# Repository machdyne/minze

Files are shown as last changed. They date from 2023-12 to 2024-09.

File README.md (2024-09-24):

# Minze Computer

Minze is an FPGA computer designed by Lone Dynamics Corporation.

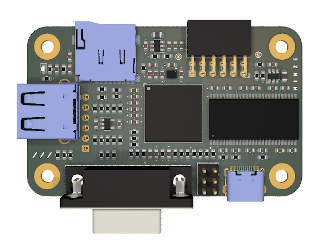
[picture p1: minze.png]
Minze Computer


This repo contains schematics, PCB layouts, pinouts, a 3D-printable case, example gateware and documentation.

Find more information on the [Minze product page](https://machdyne.com/product/minze-computer/).

## Programming Minze

Minze has a JTAG interface and ships with a [DFU bootloader](https://github.com/machdyne/tinydfu-bootloader) that allows the included flash [MMOD](https://machdyne.com/product/mmod) to be programmed over the USB-C port.

### DFU

The DFU bootloader is available for 5 seconds after power-on, issuing a DFU command during this period will stop the boot process until the DFU device is detached. If no command is received the boot process will continue and the user gateware will be loaded.

Install [dfu-util](http://dfu-util.sourceforge.net) (Debian/Ubuntu):

```
$ sudo apt install dfu-util
```

Update the user gateware on the flash MMOD:

```
$ sudo dfu-util -a 0 -D image.bit
```

Detach the DFU device and continue the boot process:

```
$ sudo dfu-util -a 0 -e
```

It is possible to update the bootloader itself using DFU but you shouldn't attempt this unless you have a JTAG programmer (or another method to program the MMOD) available, in case you need to restore the bootloader.

### JTAG

These examples assume you're using a "USB Blaster" JTAG cable, see the header pinout below. You will need to have [openFPGALoader](https://github.com/trabucayre/openFPGALoader) installed.

Program the configuration SRAM:

```
openFPGALoader -c usb-blaster image.bit
```

Program the flash MMOD:

```
openFPGALoader -f -c usb-blaster images/bootloader/tinydfu_minze.bit
```

## Blinky 

Building the blinky example requires [Yosys](https://github.com/YosysHQ/yosys), [nextpnr-ecp5](https://github.com/YosysHQ/nextpnr) and [Project Trellis](https://github.com/YosysHQ/prjtrellis).

Assuming they are installed, you can simply type `make` to build the gateware, which will be written to output/blinky.bin. You can then use [openFPGALoader](https://github.com/trabucayre/openFPGALoader) or dfu-util to write the gateware to the device.

## Linux

See the [Kakao Linux](https://github.com/machdyne/kakao) repo for the latest instructions.

### Prebuilt Images

Prebuilt gateware capable of running Linux is available in the `images/v1` directory.

These images support a serial console on the PMOD socket. You can use a standard USB-UART PMOD to access the BIOS, boot messages and serial console.

### Building Linux-capable Gateware

Please follow the setup instructions in the [linux-on-litex-vexriscv](https://github.com/litex-hub/linux-on-litex-vexriscv) repo and then:

1. Build the Linux-capable gateware:

```
$ cd linux-on-litex-vexriscv
$ ./make.py --board=minze --dcache-size=64 --icache-size=64 --uart-baudrate=115200 --build
$ ls build/minze
```

2. Write the gateware to the MMOD using USB DFU:

```
$ sudo dfu-util -a 0 -D build/minze/gateware/minze.bit
```

3. Copy the device tree binary `build/minze/minze.dtb` to a FAT-formatted MicroSD card.

## JTAG Header

The 3.3V JTAG header can be used to program the FPGA SRAM as well as the MMOD flash memory. It can also be used to provide power (5V) to the board.

```
6 5
4 3
2 1
```

| Pin | Signal |
| --- | --- |
| 1 | TCK |
| 2 | TDI |
| 3 | TDO |
| 4 | TMS |
| 5 | 5V0 |
| 6 | GND |

## Board Revisions

| Revision | Notes |
| --- | ----- |
| V1 | Initial production version |

## License

The contents of this repo are released under the [Lone Dynamics Open License](LICENSE.md) with the following exceptions:

- The KiCad design files contain parts of the [kicad-pmod](https://github.com/mithro/kicad-pmod) library which is released under the [Apache License, Version 2.0](https://www.apache.org/licenses/LICENSE-2.0.html).

- The KiCad design files may contain symbols and footprints released under other licenses; please contact us if we've failed to give proper attribution.

Note: You can use these designs for commercial purposes but we ask that instead of producing exact clones, that you either replace our trademarks and logos with your own or add your own next to ours.

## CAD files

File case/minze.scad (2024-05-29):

/*
 * Minze Case
 * Copyright (c) 2022 Lone Dynamics Corporation. All rights reserved.
 *
 * required hardware:
 *  - 4 x M3 x 25mm countersunk bolts
 *  - 4 x M3 nuts
 *
 */

$fn = 100;

board_width = 42;
board_thickness = 1.5;
board_length = 68;
board_height = 1.6;
board_spacing = 2;

wall = 1.5;

top_height = 15;
bottom_height = 10.5;

translate([wall,wall,0]) mdm_board();

translate([0,0,15])
	mdm_case_top();

translate([0,0,-15])
	mdm_case_bottom();

module mdm_board() {
	
	difference() {
		color([0,0.5,0])
			roundedcube(board_width,board_length,board_thickness,5);
		translate([5, 5, -1]) cylinder(d=3.2, h=10);
		translate([5, 68-5, -1]) cylinder(d=3.2, h=10);
		translate([42-5, 5, -1]) cylinder(d=3.2, h=10);
		translate([42-5, 68-5, -1]) cylinder(d=3.2, h=10);
	}	
	
}

module mdm_case_top() {

	// supports
	translate([wall, wall, 0]) {
		translate([40.5,53.7-(9.5/2)-1,0]) cube([1,1,14.9]);
		translate([40.5,53.7-(9.5/2)-8.45,0]) cube([1,1,14.9]);
	}
	
	difference() {
				
		color([0.5,0.5,0.5])
			roundedcube(board_width+(wall*2),board_length+(wall*2),top_height,5);

		// cutouts
			
		translate([2,9.5,-2])
			roundedcube(board_width-1.25,board_length-16,14.5,5);

		translate([9.5,2,-2])
			roundedcube(board_width-16,board_length,10.25,5);			
	
		translate([wall, wall, 0]) {

			// vents
			translate([42/2-(15/2),50,0]) rotate([0,0,-10]) cube([15,1,20]);
			translate([42/2-(15/2),45,0]) rotate([0,0,-10]) cube([15,1,20]);
			translate([42/2-(15/2),40,0]) rotate([0,0,-10]) cube([15,1,20]);			
	
			// USBC
			translate([30,53.7-(9.5/2),0]) cube([30,9.5,3.5]);

			// VGA
			translate([30,25-(31/2),-1]) cube([30,31,12.5+1]);
			
			// USBA
			translate([21-(15/2),-5,0]) cube([15,10,7.2+1]);
	
			// SD
			translate([-10,19.5-(15/2),-2]) cube([15,15,2+2]);
			
			// PMODA
			translate([-10,47.15-(16/2),0]) cube([25,16,5.1]);
			
			// bolt holes
			translate([5, 5, -21]) cylinder(d=3.5, h=40);
			translate([5, 68-5, -21]) cylinder(d=3.5, h=40);
			translate([42-5, 5, -20]) cylinder(d=3.5, h=40);
			translate([42-5, 68-5, -21]) cylinder(d=3.5, h=40);

			// flush mount bolt holes
			translate([5, 5, top_height-1.5]) cylinder(d=5.25, h=4);
			translate([5, 68-5, top_height-1.5]) cylinder(d=5.25, h=4);
			translate([42-5, 5, top_height-1.5]) cylinder(d=5.25, h=4);
			translate([42-5, 68-5, top_height-1.5]) cylinder(d=5.25, h=4);

			// minze text
			rotate(270)
				translate([-22.5,19,top_height-0.5])
					linear_extrude(1)
						text("M I N Z E", size=4, halign="center",
							font="Ubuntu:style=Bold");

		}
		
	}	
}

module mdm_case_bottom() {
	
	difference() {
		color([0.5,0.5,0.5])
			roundedcube(board_width+(wall*2),board_length+(wall*2),bottom_height,5);
		
		// cutouts
		translate([3,10,1.5])
			roundedcube(board_width-3,board_length-17,10,5);
				
		translate([10.5,2.5,1.5])
			roundedcube(board_width-17.5,board_length-2,10,5);

		translate([wall, wall, 0]) {
			
		// board cutout
		translate([0,0,bottom_height-board_height])
			roundedcube(board_width+0.2,board_length+0.2,board_height+1,2.5);

		translate([wall, wall, 0]) {

			// USBC
			translate([30.5,43,5]) cube([10.20,15,10.5+1]);

		}

		// bolt holes
		translate([5, 5, -11]) cylinder(d=3.2, h=25);
		translate([5, 68-5, -11]) cylinder(d=3.2, h=25);
		translate([42-5, 5, -11]) cylinder(d=3.2, h=25);
		translate([42-5, 68-5, -11]) cylinder(d=3.2, h=25);

		// nut holes
		translate([5, 5, -0.75]) cylinder(d=7, h=4, $fn=6);
		translate([5, 68-5, -0.75]) cylinder(d=7, h=4, $fn=6);
		translate([42-5, 5, -0.75]) cylinder(d=7, h=4, $fn=6);
		translate([42-5, 68-5, -0.75]) cylinder(d=7, h=4, $fn=6);

		}
		
	}	
}

// https://gist.github.com/tinkerology/ae257c5340a33ee2f149ff3ae97d9826
module roundedcube(xx, yy, height, radius)
{
    translate([0,0,height/2])
    hull()
    {
        translate([radius,radius,0])
        cylinder(height,radius,radius,true);

        translate([xx-radius,radius,0])
        cylinder(height,radius,radius,true);

        translate([xx-radius,yy-radius,0])
        cylinder(height,radius,radius,true);

        translate([radius,yy-radius,0])
        cylinder(height,radius,radius,true);
    }
}

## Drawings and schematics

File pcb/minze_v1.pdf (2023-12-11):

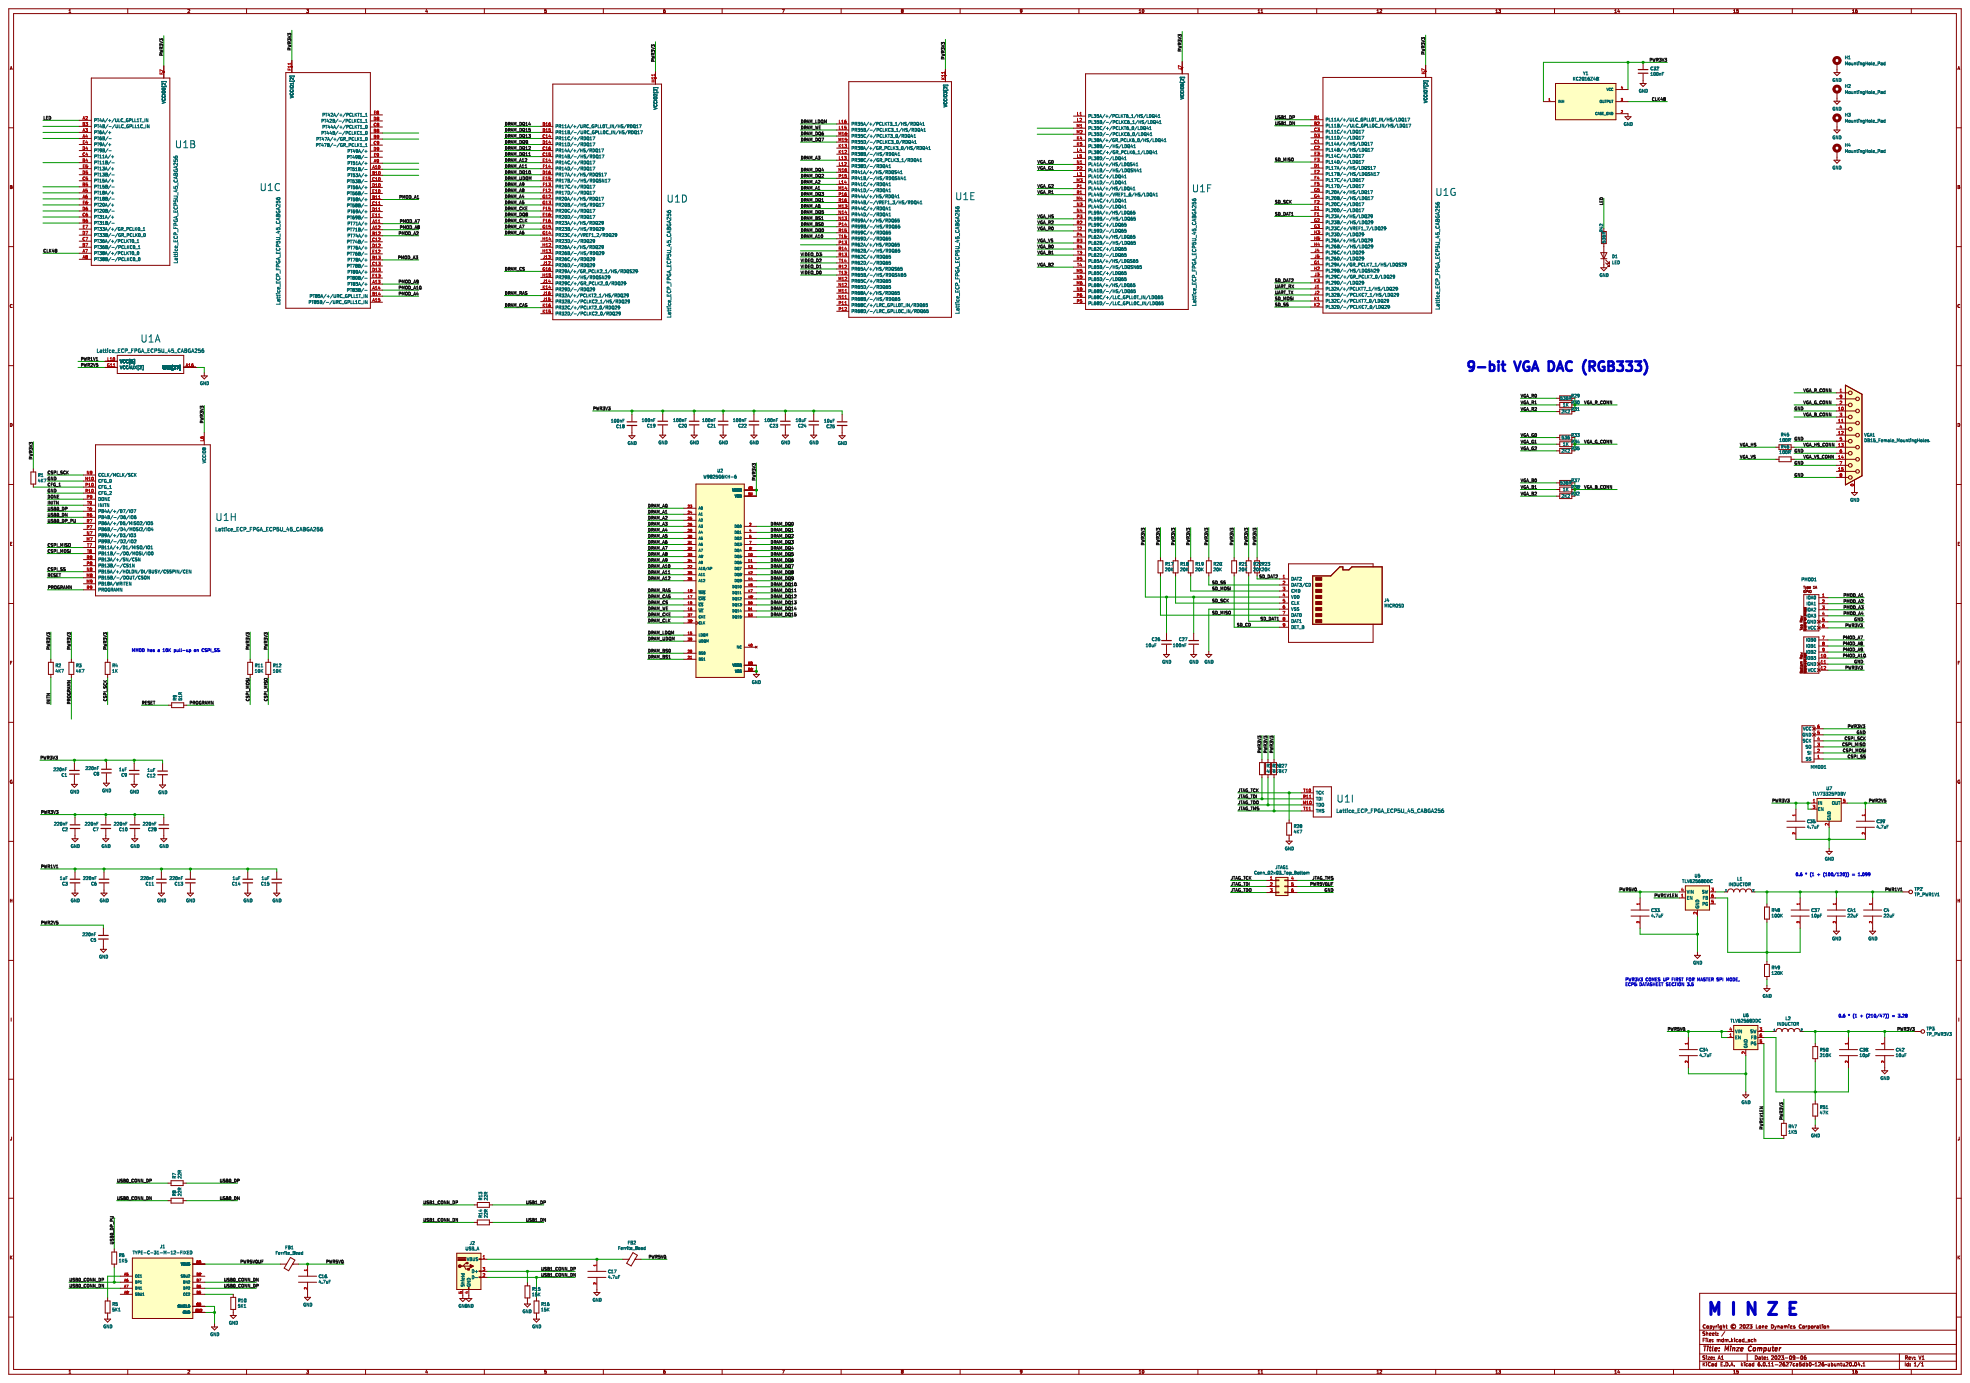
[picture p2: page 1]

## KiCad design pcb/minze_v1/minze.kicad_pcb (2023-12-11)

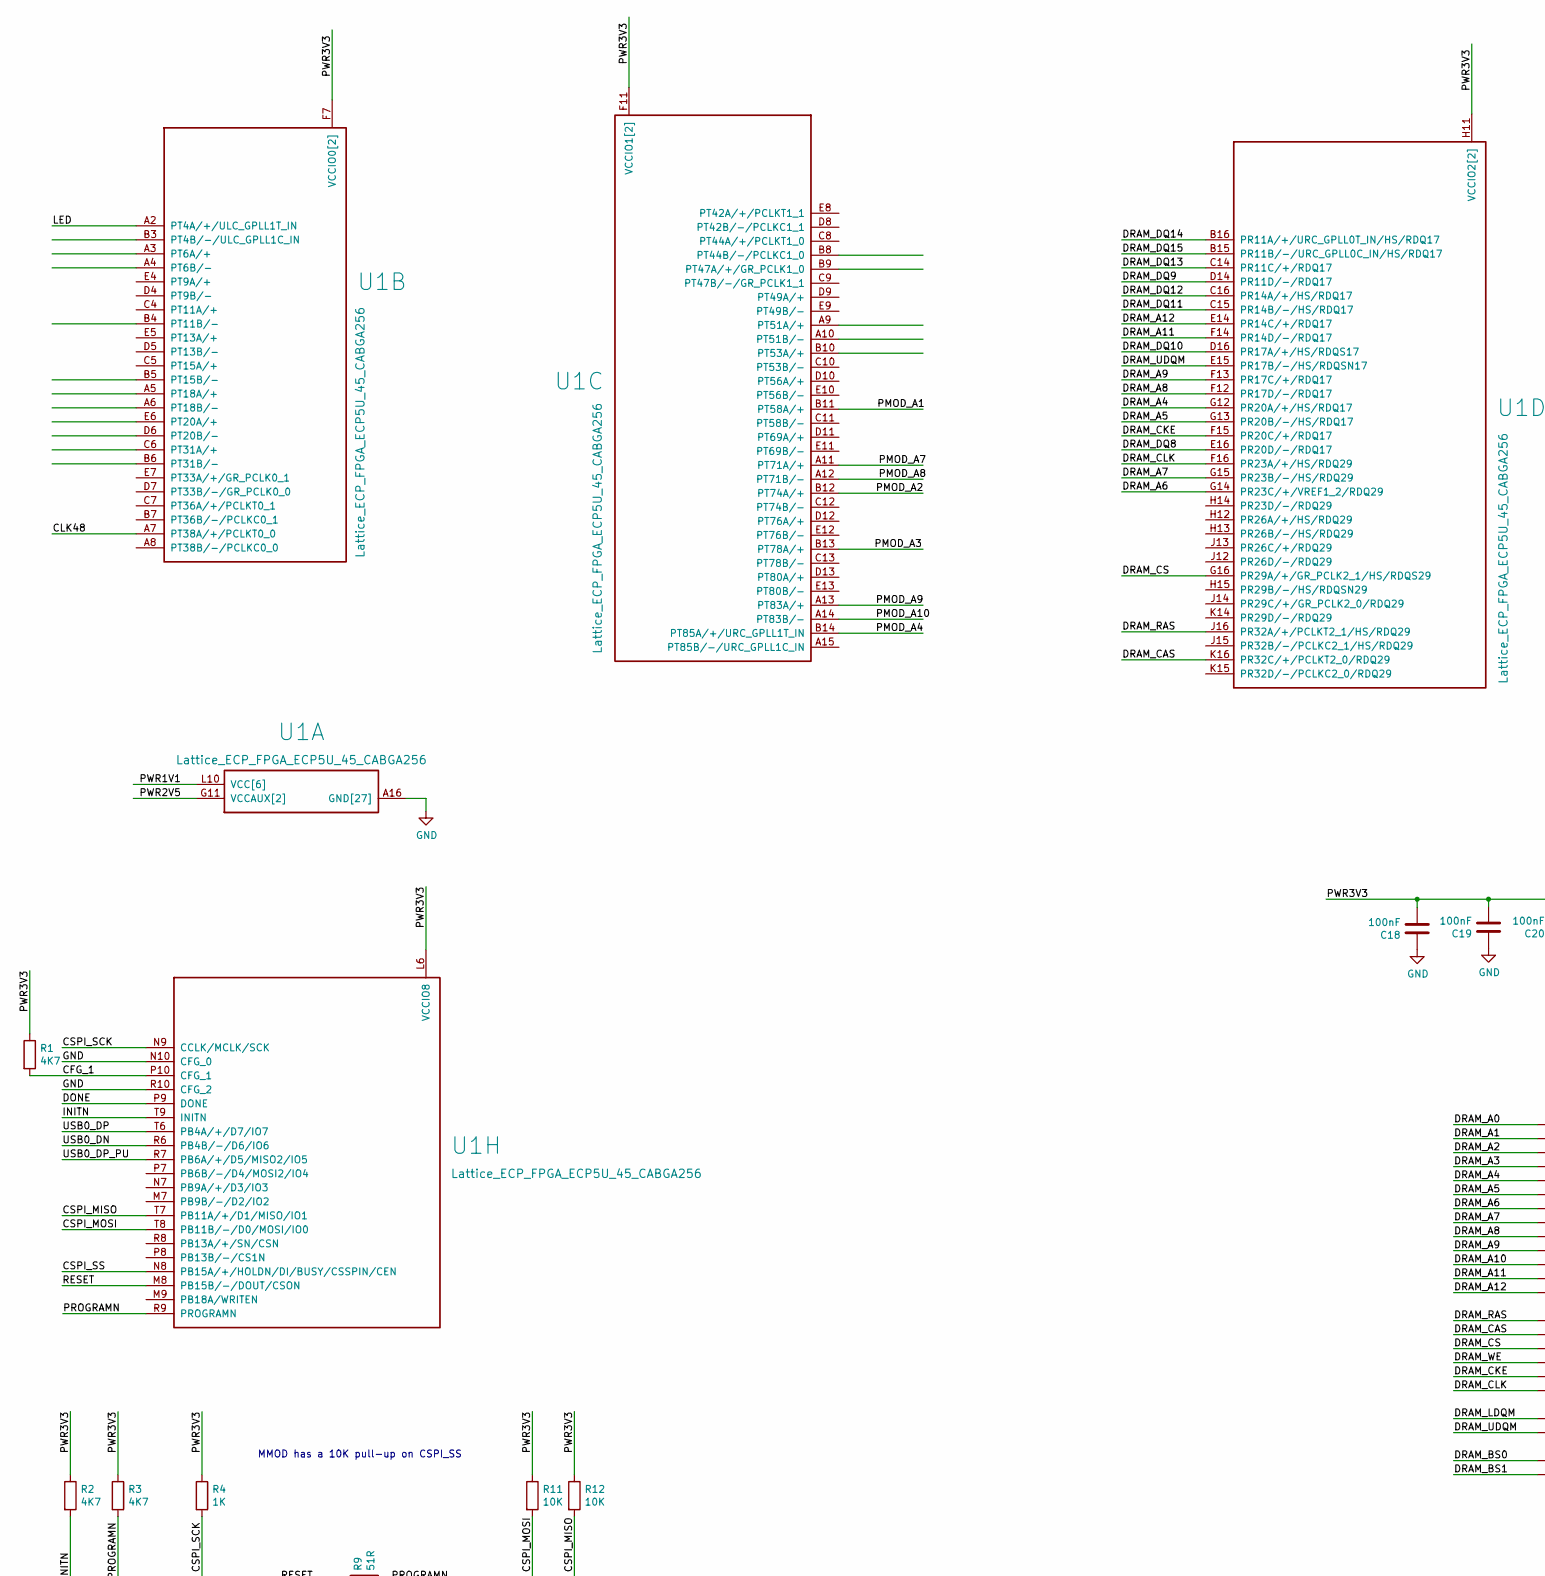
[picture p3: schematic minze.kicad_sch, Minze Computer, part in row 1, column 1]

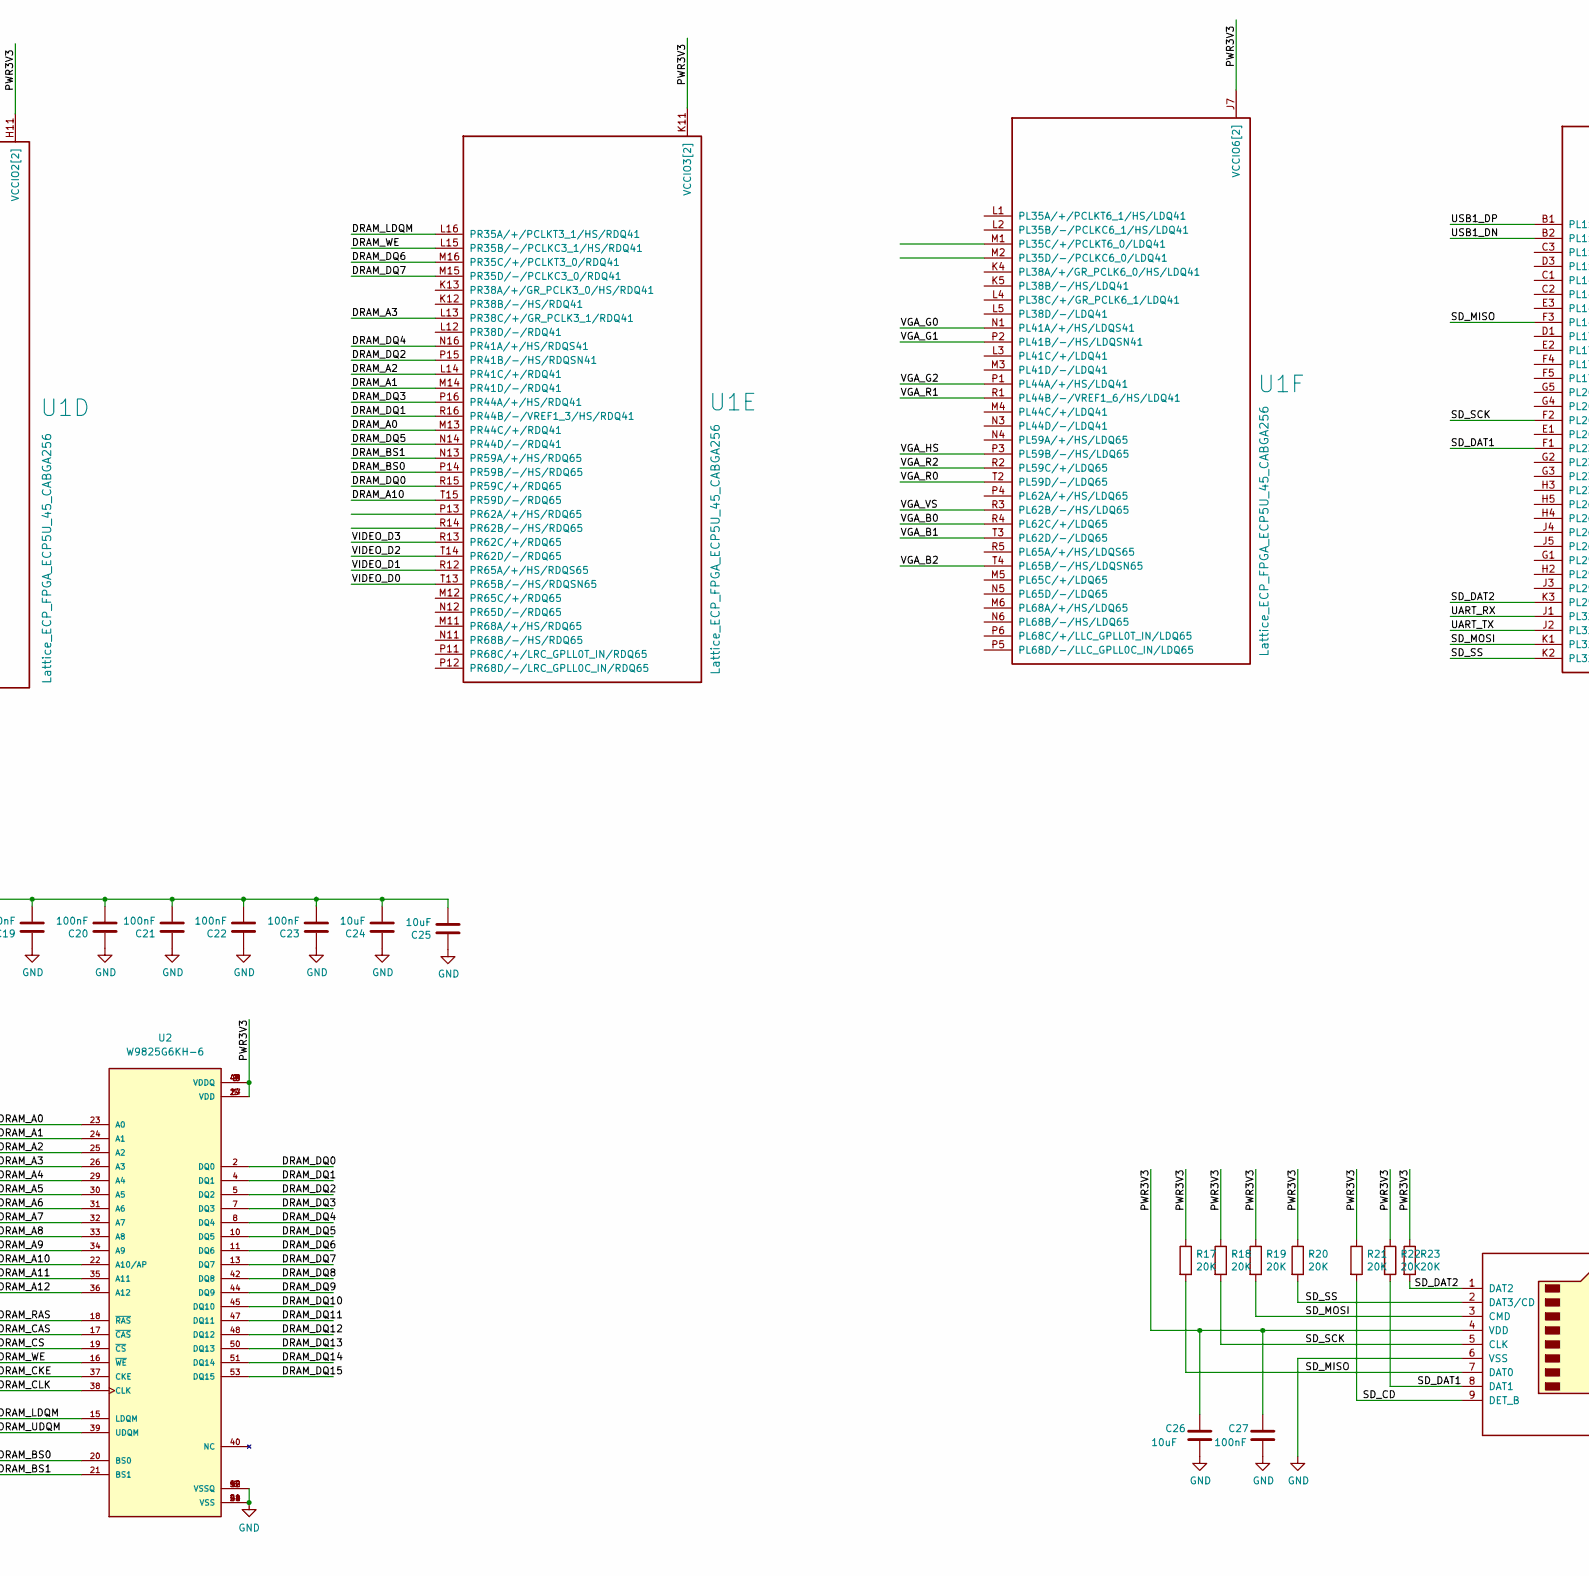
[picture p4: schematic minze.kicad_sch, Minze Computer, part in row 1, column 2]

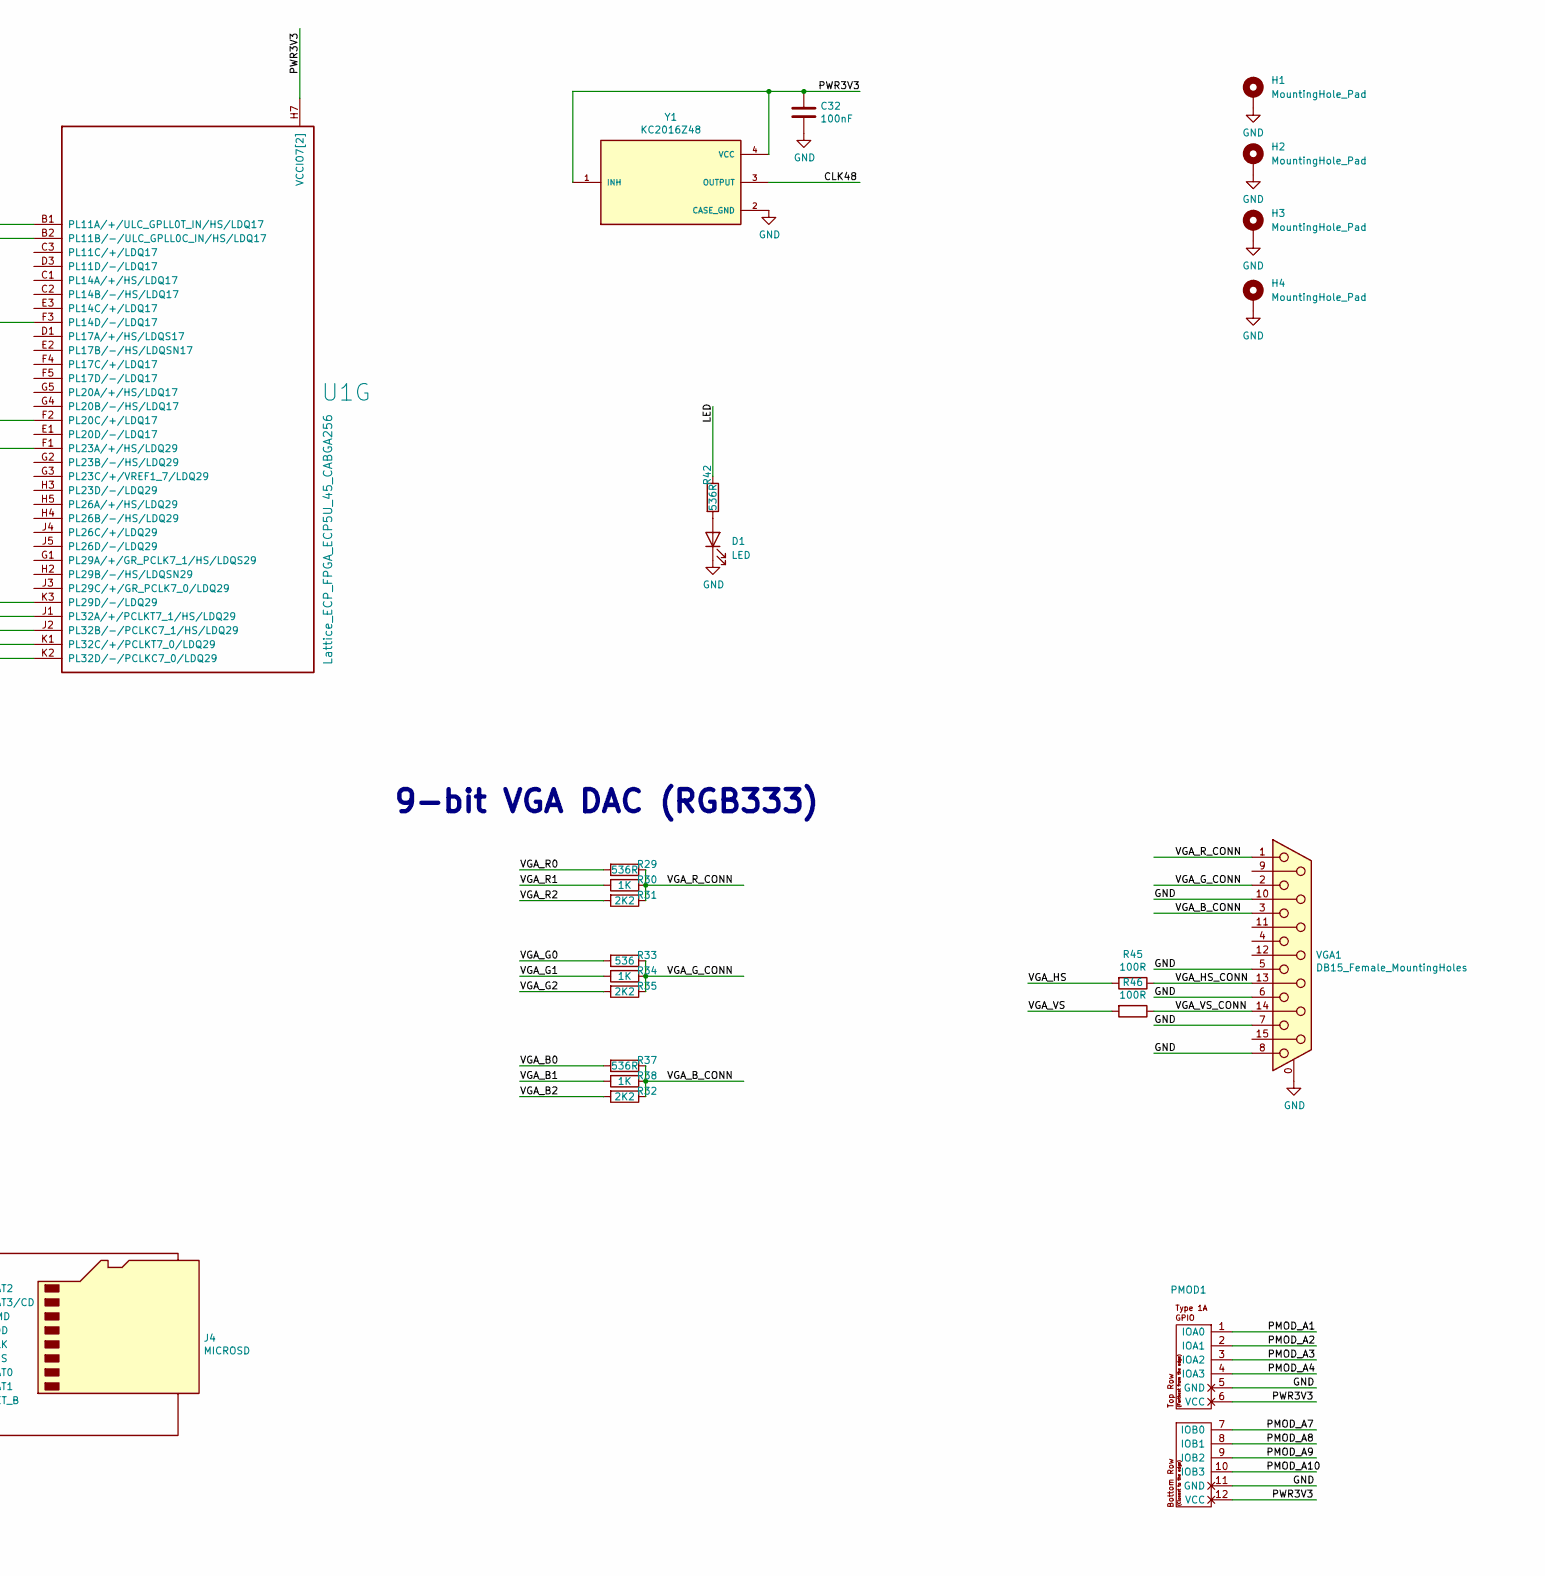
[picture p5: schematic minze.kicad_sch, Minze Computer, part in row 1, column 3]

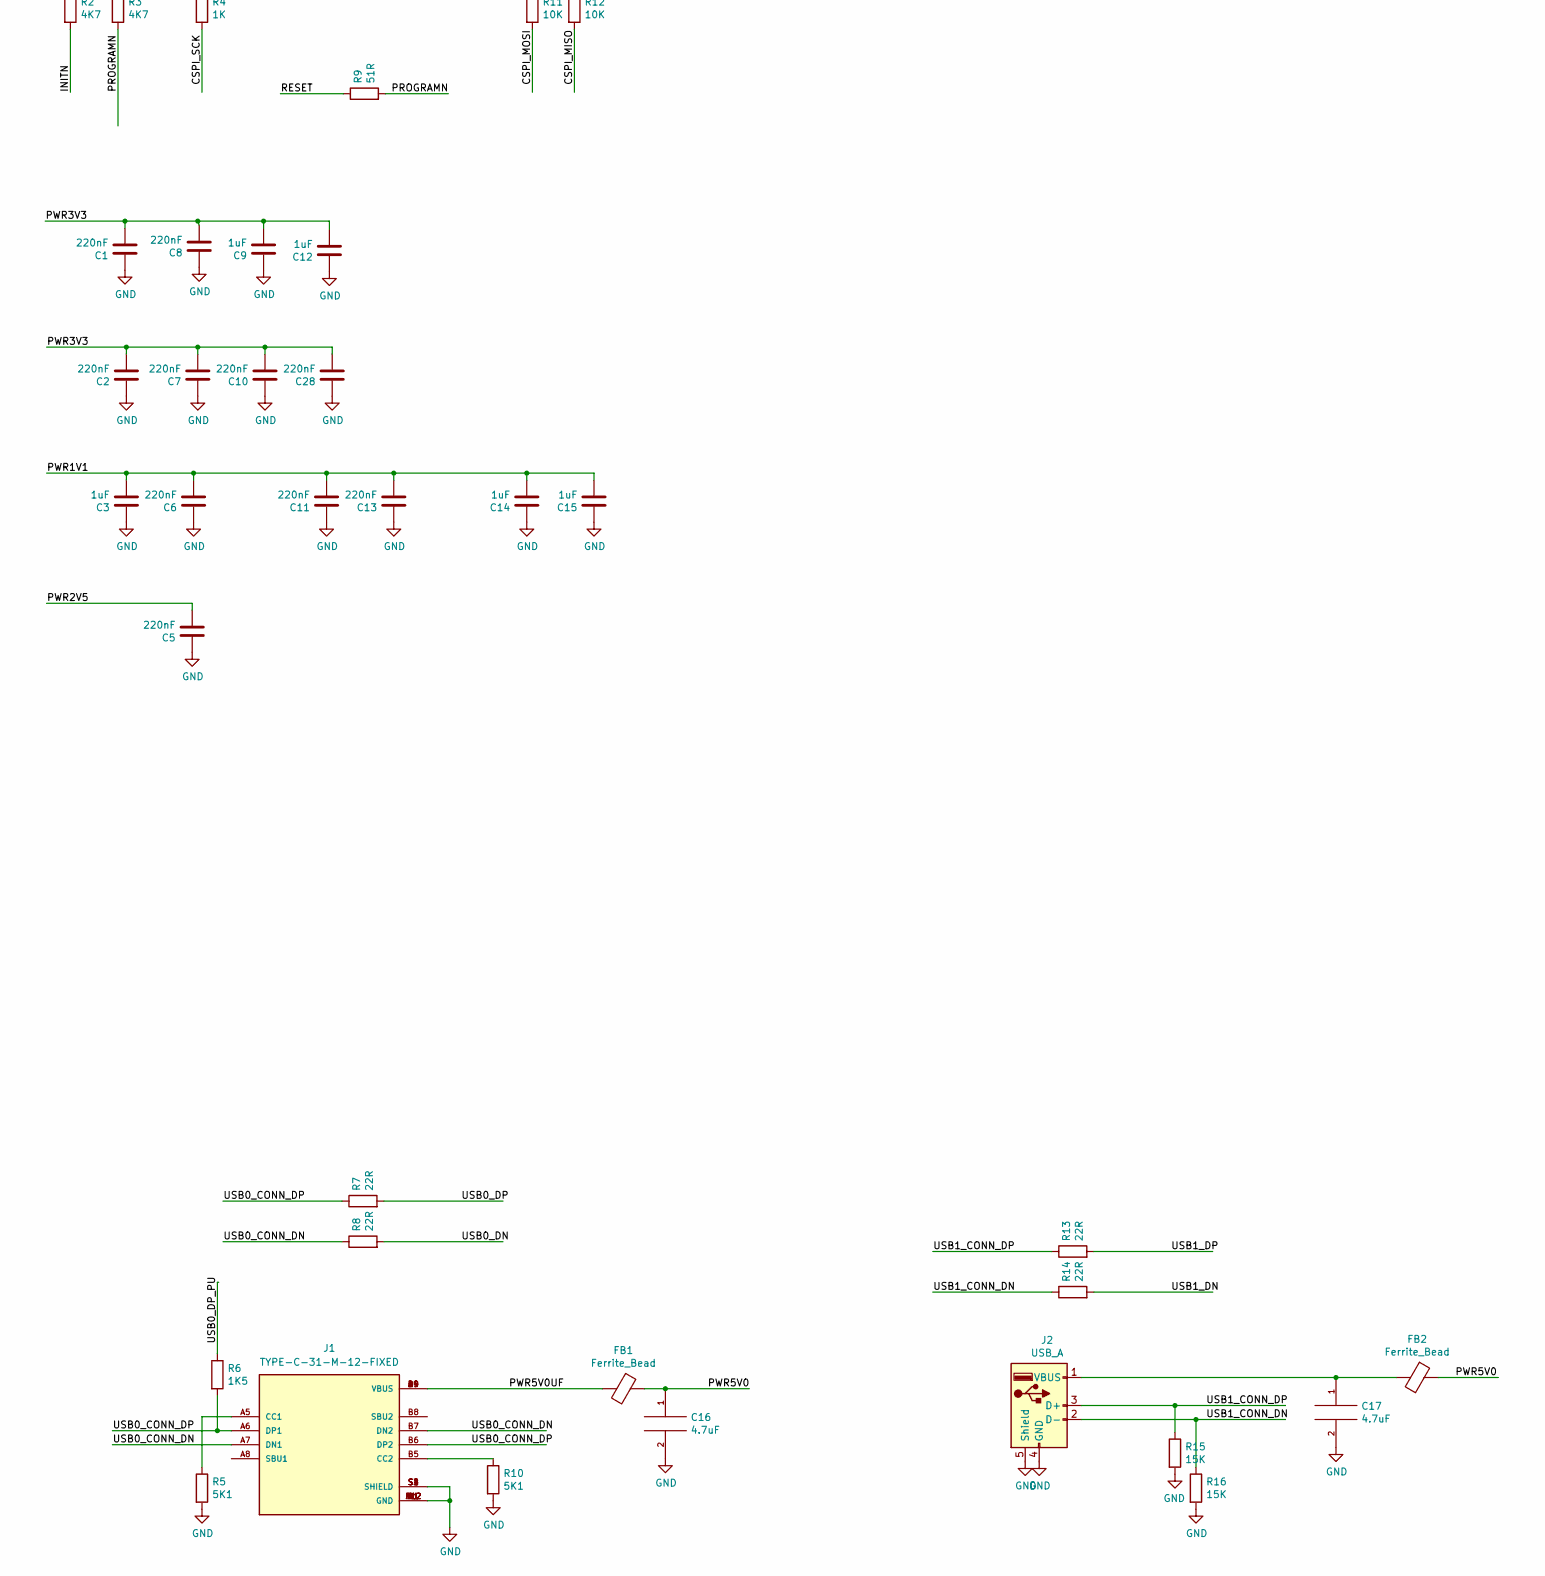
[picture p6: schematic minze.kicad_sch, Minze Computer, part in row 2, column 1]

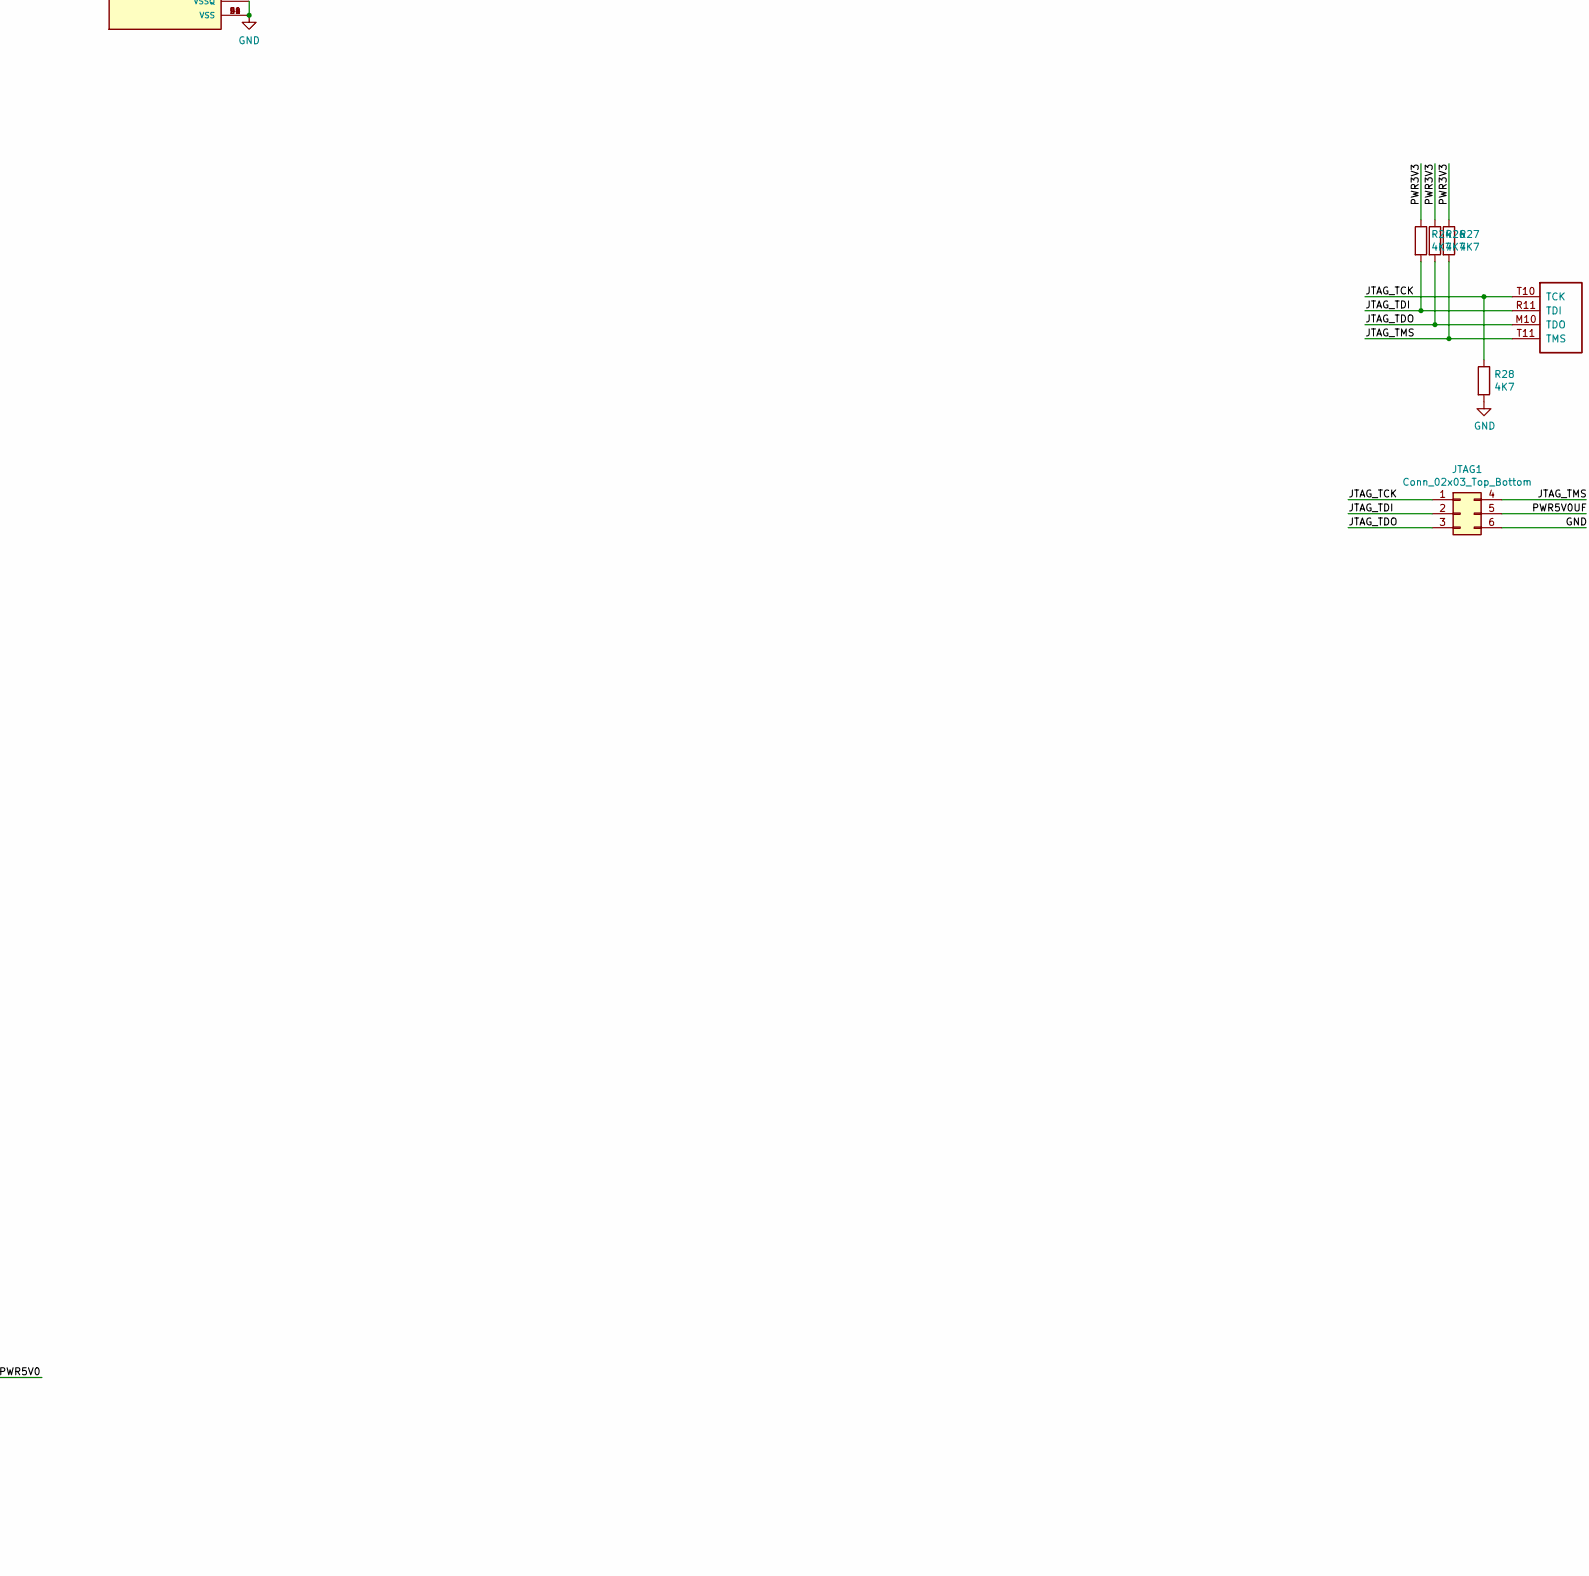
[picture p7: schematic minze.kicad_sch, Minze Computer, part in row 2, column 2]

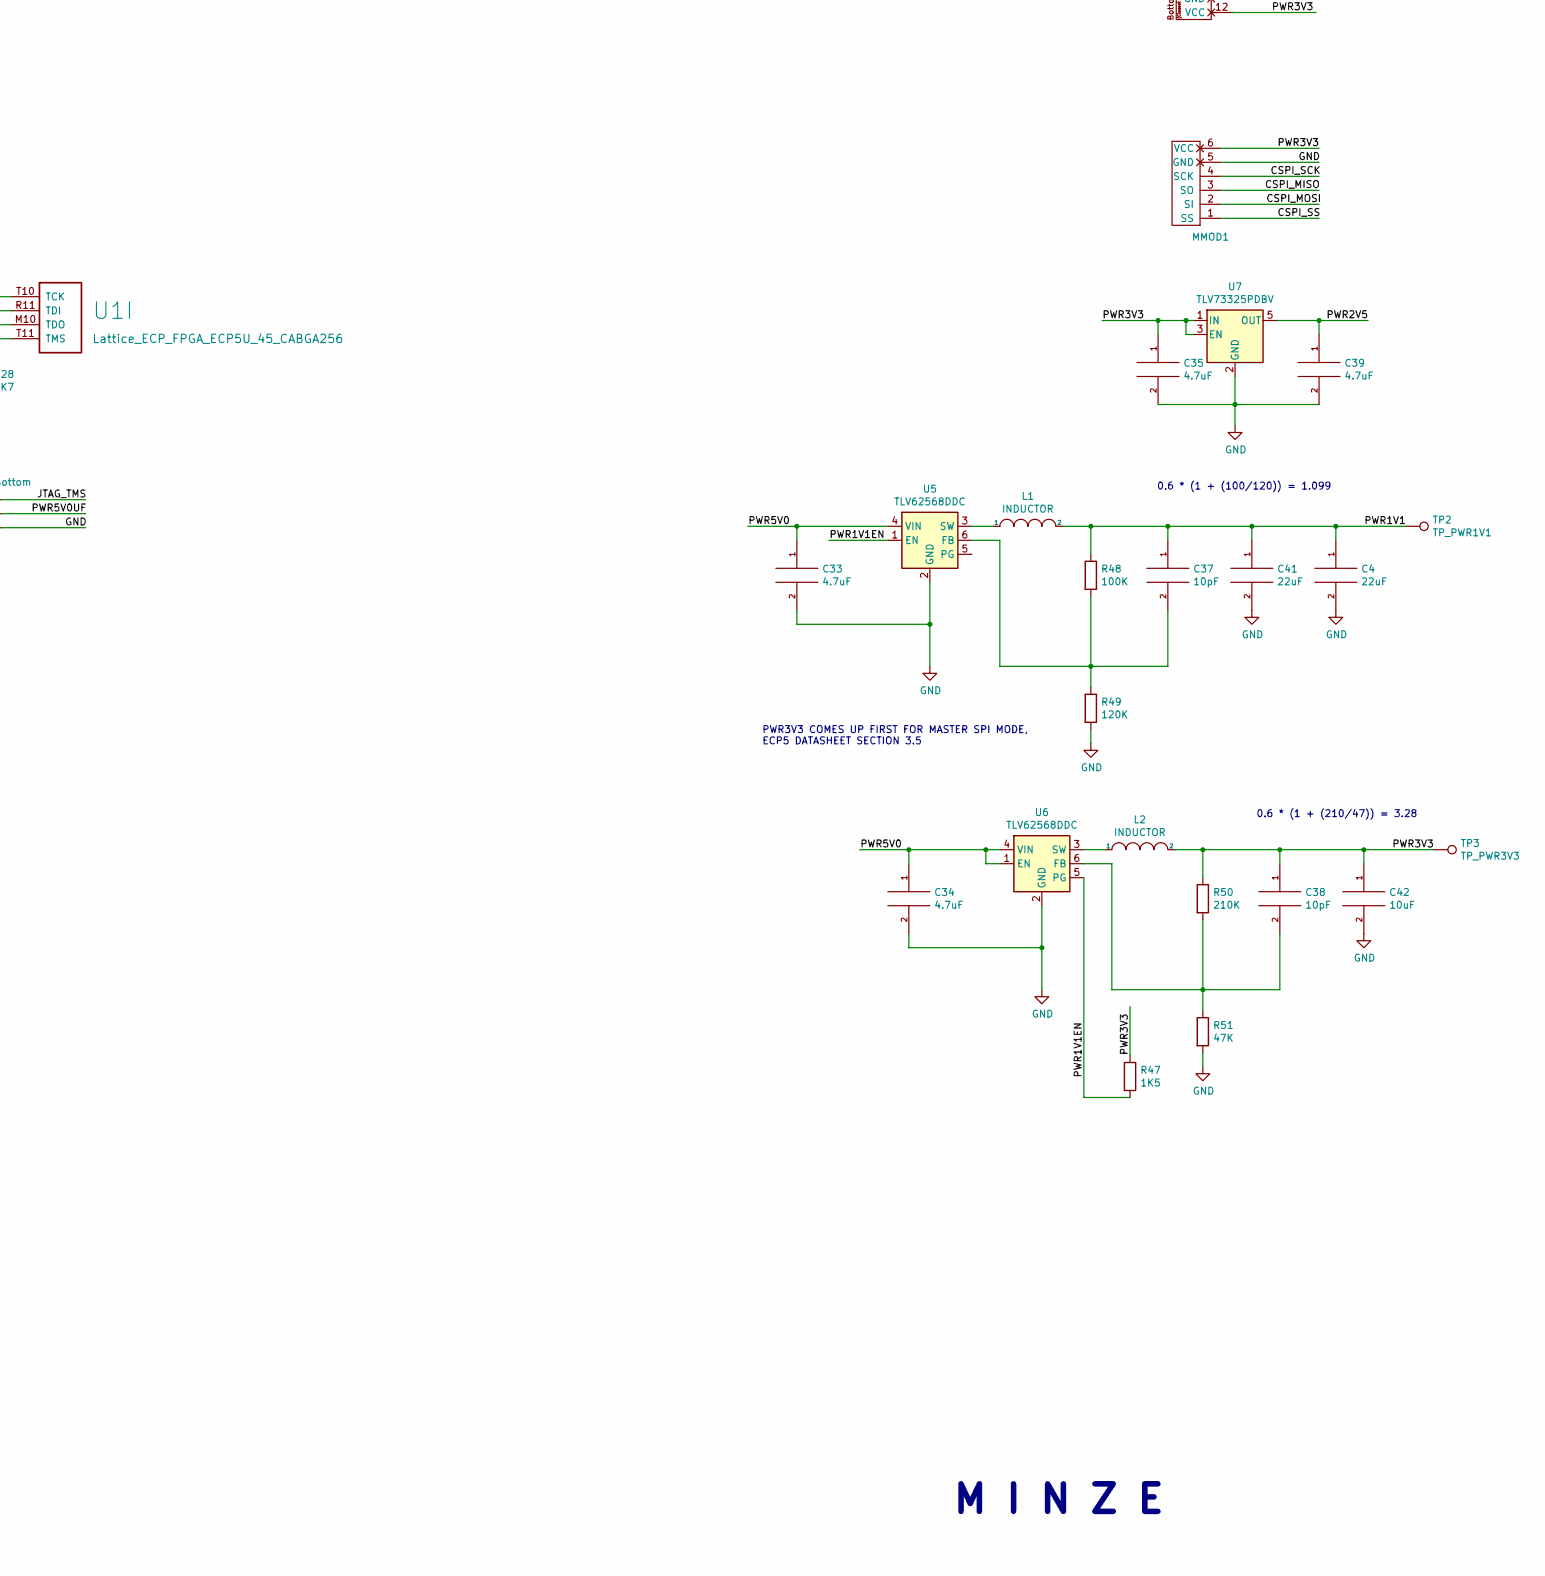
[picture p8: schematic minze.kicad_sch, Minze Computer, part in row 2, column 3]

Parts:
C1, C2, C5, C6, C7, C8, C10, C11, C13, C28: 220nF; C_0603_1608Metric
C3, C9, C12, C14, C15: 1uF; C_0603_1608Metric
C4, C41: 22uF; C_0603_1608Metric
C16, C17, C33, C34, C35, C39: 4.7uF; C_0603_1608Metric
C18, C19, C20, C21, C22, C23, C27, C32: 100nF; C_0603_1608Metric
C24, C25, C26, C42: 10uF; C_0603_1608Metric
C37, C38: 10pF; C_0603_1608Metric
D1: LED; LED_0603_1608Metric
FB1, FB2: Ferrite_Bead; R_0603_1608Metric
H1, H2, H3, H4: MountingHole_Pad; MountingHole_3.2mm_M3_Pad
J1: TYPE-C-31-M-12-FIXED; USB_C_Receptacle_HRO_TYPE-C-31-M-12-BIG-PADS; PARTREV A
J2: USB_A; USB_A_Stewart_SS-52100-001_Horizontal
J4: MICROSD; SDCARD
JTAG1: Conn_02x03_Top_Bottom; PinHeader_2x03_P2.54mm_Vertical
L1, L2: INDUCTOR; L_0805_2012Metric
MMOD1: PMOD-Device-x1-Type-2-SPI; MMOD_Host_Socket
PMOD1: PMOD-Device-x2-Type-1A-GPIO; PMOD_2x06_HOST
R1, R2, R3, R24, R26, R27, R28: 4K7; R_0603_1608Metric
R4, R30, R34, R38: 1K; R_0603_1608Metric
R5, R10: 5K1; R_0603_1608Metric
R6, R47: 1K5; R_0603_1608Metric
R7, R8, R13, R14: 22R; R_0603_1608Metric
R9: 51R; R_0603_1608Metric
R11, R12: 10K; R_0603_1608Metric
R15, R16: 15K; R_0603_1608Metric
R17, R18, R19, R20, R21, R22, R23: 20K; R_0603_1608Metric
R29, R37, R42: 536R; R_0603_1608Metric
R31, R32, R35: 2K2; R_0603_1608Metric
R33: 536; R_0603_1608Metric
R45, R46: 100R; R_0603_1608Metric
R48: 100K; R_0603_1608Metric
R49: 120K; R_0603_1608Metric
R50: 210K; R_0603_1608Metric
R51: 47K; R_0603_1608Metric
TP2: TP_PWR1V1; TestPoint_THTPad_D1.0mm_Drill0.5mm
TP3: TP_PWR3V3; TestPoint_THTPad_D1.0mm_Drill0.5mm
U1: Lattice_ECP_FPGA_ECP5U_45_CABGA256; BGA-256_14.0x14.0mm_Layout16x16_P0.8mm_Ball0.45mm_Pad0.32mm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
U2: W9825G6KH-6; SOP80P1176X120-54N; PARTREV A05
U5, U6: TLV62568DDC; SOT-23-6
U7: TLV73325PDBV; SOT-23-5
VGA1: DB15_Female_MountingHoles; DSUB-15-HD_Female_Horizontal_P2.29x1.98mm_EdgePinOffset3.03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
Y1: KC2016Z48; OSC_KC2016Z13.5600C1KX00; PARTREV November 2020

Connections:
/CFG_1: R1.2, U1.P10 (CFG_1)
/CLK48: U1.A7 (PT38A/+/PCLKT0_0), Y1.3 (OUTPUT)
/CSPI_MISO: MMOD1.3 (SO), R12.2, U1.T7 (PB11A/+/D1/MISO/IO1)
/CSPI_MOSI: MMOD1.2 (SI), R11.2, U1.T8 (PB11B/-/D0/MOSI/IO0)
/CSPI_SCK: MMOD1.4 (SCK), R4.2, U1.N9 (CCLK/MCLK/SCK)
/CSPI_SS: MMOD1.1 (SS), U1.N8 (PB15A/+/HOLDN/DI/BUSY/CSSPIN/CEN)
/DONE: U1.P9 (DONE)
/DRAM_A0: U1.M13 (PR44C/+/RDQ41), U2.23 (A0)
/DRAM_A1: U1.M14 (PR41D/-/RDQ41), U2.24 (A1)
/DRAM_A2: U1.L14 (PR41C/+/RDQ41), U2.25 (A2)
/DRAM_A3: U1.L13 (PR38C/+/GR_PCLK3_1/RDQ41), U2.26 (A3)
/DRAM_A4: U1.G12 (PR20A/+/HS/RDQ17), U2.29 (A4)
/DRAM_A5: U1.G13 (PR20B/-/HS/RDQ17), U2.30 (A5)
/DRAM_A6: U1.G14 (PR23C/+/VREF1_2/RDQ29), U2.31 (A6)
/DRAM_A7: U1.G15 (PR23B/-/HS/RDQ29), U2.32 (A7)
/DRAM_A8: U1.F12 (PR17D/-/RDQ17), U2.33 (A8)
/DRAM_A9: U1.F13 (PR17C/+/RDQ17), U2.34 (A9)
/DRAM_A10: U1.T15 (PR59D/-/RDQ65), U2.22 (A10/AP)
/DRAM_A11: U1.F14 (PR14D/-/RDQ17), U2.35 (A11)
/DRAM_A12: U1.E14 (PR14C/+/RDQ17), U2.36 (A12)
/DRAM_BS0: U1.P14 (PR59B/-/HS/RDQ65), U2.20 (BS0)
/DRAM_BS1: U1.N13 (PR59A/+/HS/RDQ65), U2.21 (BS1)
/DRAM_CAS: U1.K16 (PR32C/+/PCLKT2_0/RDQ29), U2.17 (~CAS)
/DRAM_CKE: U1.F15 (PR20C/+/RDQ17), U2.37 (CKE)
/DRAM_CLK: U1.F16 (PR23A/+/HS/RDQ29), U2.38 (CLK)
/DRAM_CS: U1.G16 (PR29A/+/GR_PCLK2_1/HS/RDQS29), U2.19 (~CS)
/DRAM_DQ0: U1.R15 (PR59C/+/RDQ65), U2.2 (DQ0)
/DRAM_DQ1: U1.R16 (PR44B/-/VREF1_3/HS/RDQ41), U2.4 (DQ1)
/DRAM_DQ2: U1.P15 (PR41B/-/HS/RDQSN41), U2.5 (DQ2)
/DRAM_DQ3: U1.P16 (PR44A/+/HS/RDQ41), U2.7 (DQ3)
/DRAM_DQ4: U1.N16 (PR41A/+/HS/RDQS41), U2.8 (DQ4)
/DRAM_DQ5: U1.N14 (PR44D/-/RDQ41), U2.10 (DQ5)
/DRAM_DQ6: U1.M16 (PR35C/+/PCLKT3_0/RDQ41), U2.11 (DQ6)
/DRAM_DQ7: U1.M15 (PR35D/-/PCLKC3_0/RDQ41), U2.13 (DQ7)
/DRAM_DQ8: U1.E16 (PR20D/-/RDQ17), U2.42 (DQ8)
/DRAM_DQ9: U1.D14 (PR11D/-/RDQ17), U2.44 (DQ9)
/DRAM_DQ10: U1.D16 (PR17A/+/HS/RDQS17), U2.45 (DQ10)
/DRAM_DQ11: U1.C15 (PR14B/-/HS/RDQ17), U2.47 (DQ11)
/DRAM_DQ12: U1.C16 (PR14A/+/HS/RDQ17), U2.48 (DQ12)
/DRAM_DQ13: U1.C14 (PR11C/+/RDQ17), U2.50 (DQ13)
/DRAM_DQ14: U1.B16 (PR11A/+/URC_GPLL0T_IN/HS/RDQ17), U2.51 (DQ14)
/DRAM_DQ15: U1.B15 (PR11B/-/URC_GPLL0C_IN/HS/RDQ17), U2.53 (DQ15)
/DRAM_LDQM: U1.L16 (PR35A/+/PCLKT3_1/HS/RDQ41), U2.15 (LDQM)
/DRAM_RAS: U1.J16 (PR32A/+/PCLKT2_1/HS/RDQ29), U2.18 (~RAS)
/DRAM_UDQM: U1.E15 (PR17B/-/HS/RDQSN17), U2.39 (UDQM)
/DRAM_WE: U1.L15 (PR35B/-/PCLKC3_1/HS/RDQ41), U2.16 (~WE)
/INITN: R2.2, U1.T9 (INITN)
/JTAG_TCK: JTAG1.1, R28.1, U1.T10 (TCK)
/JTAG_TDI: JTAG1.2, R24.2, U1.R11 (TDI)
/JTAG_TDO: JTAG1.3, R26.2, U1.M10 (TDO)
/JTAG_TMS: JTAG1.4, R27.2, U1.T11 (TMS)
/LED: R42.1, U1.A2 (PT4A/+/ULC_GPLL1T_IN)
/PMOD_A1: PMOD1.1 (IOA0), U1.B11 (PT58A/+)
/PMOD_A2: PMOD1.2 (IOA1), U1.B12 (PT74A/+)
/PMOD_A3: PMOD1.3 (IOA2), U1.B13 (PT78A/+)
/PMOD_A4: PMOD1.4 (IOA3), U1.B14 (PT85A/+/URC_GPLL1T_IN)
/PMOD_A7: PMOD1.7 (IOB0), U1.A11 (PT71A/+)
/PMOD_A8: PMOD1.8 (IOB1), U1.A12 (PT71B/-)
/PMOD_A9: PMOD1.9 (IOB2), U1.A13 (PT83A/+)
/PMOD_A10: PMOD1.10 (IOB3), U1.A14 (PT83B/-)
/PROGRAMN: R3.2, R9.2, U1.R9 (PROGRAMN)
/PWR1V1: C3.2, C4.1, C6.2, C11.2, C13.2, C14.2, C15.2, C37.1, C41.1, L1.2, R48.1, TP2.1, U1.G6 (VCC[6]), U1.G7 (VCC[6]), U1.G9 (VCC[6]), U1.L8 (VCC[6]), U1.L9 (VCC[6]), U1.L10 (VCC[6])
/PWR1V1EN: R47.2, U5.1 (EN), U6.5 (PG)
/PWR2V5: C5.2, C39.1, U1.G11 (VCCAUX[2]), U1.L7 (VCCAUX[2]), U7.5 (OUT)
/PWR3V3: C1.2, C2.2, C7.2, C8.2, C9.2, C10.2, C12.2, C18.2, C19.2, C20.2, C21.2, C22.2, C23.2, C24.2, C25.2, C26.1, C27.1, C28.2, C32.1, C35.1, C38.1, C42.1, J4.4 (VDD), L2.2, MMOD1.6 (VCC), PMOD1.6 (VCC), PMOD1.12 (VCC), R1.1, R2.1, R3.1, R4.1, R11.1, R12.1, R17.1, R18.1, R19.1, R20.1, R21.1, R22.1, R23.1, R24.1, R26.1, R27.1, R47.1, R50.1, TP3.1, U1.F6 (VCCIO0[2]), U1.F7 (VCCIO0[2]), U1.F10 (VCCIO1[2]), U1.F11 (VCCIO1[2]), U1.H6 (VCCIO7[2]), U1.H7 (VCCIO7[2]), U1.H11 (VCCIO2[2]), U1.J6 (VCCIO6[2]), U1.J7 (VCCIO6[2]), U1.J11 (VCCIO2[2]), U1.K11 (VCCIO3[2]), U1.L6 (VCCIO8), U1.L11 (VCCIO3[2]), U2.1 (VDD), U2.3 (VDDQ), U2.9 (VDDQ), U2.14 (VDD), U2.27 (VDD), U2.43 (VDDQ), U2.49 (VDDQ), U7.1 (IN), U7.3 (EN), Y1.1 (INH), Y1.4 (VCC)
/PWR5V0: C16.1, C33.1, C34.1, FB1.1, FB2.1, U5.4 (VIN), U6.1 (EN), U6.4 (VIN)
/PWR5V0UF: FB1.2, J1.A4 (VBUS), J1.A9 (VBUS), J1.B4 (VBUS), J1.B9 (VBUS), JTAG1.5
/RESET: R9.1, U1.M8 (PB15B/-/DOUT/CSON)
/SD_CD: J4.9 (DET_B), R21.2
/SD_DAT1: J4.8 (DAT1), R22.2, U1.F1 (PL23A/+/HS/LDQ29)
/SD_DAT2: J4.1 (DAT2), R23.2, U1.K3 (PL29D/-/LDQ29)
/SD_MISO: J4.7 (DAT0), R17.2, U1.F3 (PL14D/-/LDQ17)
/SD_MOSI: J4.3 (CMD), R19.2, U1.K1 (PL32C/+/PCLKT7_0/LDQ29)
/SD_SCK: J4.5 (CLK), R18.2, U1.F2 (PL20C/+/LDQ17)
/SD_SS: J4.2 (DAT3/CD), R20.2, U1.K2 (PL32D/-/PCLKC7_0/LDQ29)
/UART_RX: U1.J1 (PL32A/+/PCLKT7_1/HS/LDQ29)
/UART_TX: U1.J2 (PL32B/-/PCLKC7_1/HS/LDQ29)
/USB0_CONN_DN: J1.A7 (DN1), J1.B7 (DN2), R8.1
/USB0_CONN_DP: J1.A6 (DP1), J1.B6 (DP2), R6.2, R7.1
/USB0_DN: R8.2, U1.R6 (PB4B/-/D6/IO6)
/USB0_DP: R7.2, U1.T6 (PB4A/+/D7/IO7)
/USB0_DP_PU: R6.1, U1.R7 (PB6A/+/D5/MISO2/IO5)
/USB1_CONN_DN: J2.2 (D-), R14.1, R16.1
/USB1_CONN_DP: J2.3 (D+), R13.1, R15.1
/USB1_DN: R14.2, U1.B2 (PL11B/-/ULC_GPLL0C_IN/HS/LDQ17)
/USB1_DP: R13.2, U1.B1 (PL11A/+/ULC_GPLL0T_IN/HS/LDQ17)
/VGA_B0: R37.2, U1.R4 (PL62C/+/LDQ65)
/VGA_B1: R38.2, U1.T3 (PL62D/-/LDQ65)
/VGA_B2: R32.2, U1.T4 (PL65B/-/HS/LDQSN65)
/VGA_B_CONN: R32.1, R37.1, R38.1, VGA1.3
/VGA_G0: R33.2, U1.N1 (PL41A/+/HS/LDQS41)
/VGA_G1: R34.2, U1.P2 (PL41B/-/HS/LDQSN41)
/VGA_G2: R35.2, U1.P1 (PL44A/+/HS/LDQ41)
/VGA_G_CONN: R33.1, R34.1, R35.1, VGA1.2
/VGA_HS: R45.2, U1.P3 (PL59B/-/HS/LDQ65)
/VGA_HS_CONN: R45.1, VGA1.13
/VGA_R0: R29.2, U1.T2 (PL59D/-/LDQ65)
/VGA_R1: R30.2, U1.R1 (PL44B/-/VREF1_6/HS/LDQ41)
/VGA_R2: R31.2, U1.R2 (PL59C/+/LDQ65)
/VGA_R_CONN: R29.1, R30.1, R31.1, VGA1.1
/VGA_VS: R46.2, U1.R3 (PL62B/-/HS/LDQ65)
/VGA_VS_CONN: R46.1, VGA1.14
/VIDEO_D0: U1.T13 (PR65B/-/HS/RDQSN65)
/VIDEO_D1: U1.R12 (PR65A/+/HS/RDQS65)
/VIDEO_D2: U1.T14 (PR62D/-/RDQ65)
/VIDEO_D3: U1.R13 (PR62C/+/RDQ65)
GND: C1.1, C2.1, C3.1, C4.2, C5.1, C6.1, C7.1, C8.1, C9.1, C10.1, C11.1, C12.1, C13.1, C14.1, C15.1, C16.2, C17.2, C18.1, C19.1, C20.1, C21.1, C22.1, C23.1, C24.1, C25.1, C26.2, C27.2, C28.1, C32.2, C33.2, C34.2, C35.2, C39.2, C41.2, C42.2, D1.1 (K), H1.1, H2.1, H3.1, H4.1, J1.A1 (GND), J1.A12 (GND), J1.B1 (GND), J1.B12 (GND), J1.S1 (SHIELD), J1.S2 (SHIELD), J1.S3 (SHIELD), J1.S4 (SHIELD), J2.4 (GND), J2.5 (Shield), J4.6 (VSS), JTAG1.6, MMOD1.5 (GND), PMOD1.5 (GND), PMOD1.11 (GND), R5.2, R10.2, R15.2, R16.2, R28.2, R49.2, R51.2, U1.A1 (GND[27]), U1.A16 (GND[27]), U1.D2 (GND[27]), U1.D15 (GND[27]), U1.F8 (GND[27]), U1.F9 (GND[27]), U1.G8 (GND[27]), U1.G10 (GND[27]), U1.H1 (GND[27]), U1.H8 (GND[27]), U1.H9 (GND[27]), U1.H10 (GND[27]), U1.H16 (GND[27]), U1.J8 (GND[27]), U1.J9 (GND[27]), U1.J10 (GND[27]), U1.K6 (GND[27]), U1.K7 (GND[27]), U1.K8 (GND[27]), U1.K9 (GND[27]), U1.K10 (GND[27]), U1.N2 (GND[27]), U1.N10 (CFG_0), U1.N15 (GND[27]), U1.R10 (CFG_2), U1.T1 (GND[27]), U1.T5 (GND[27]), U1.T12 (GND[27]), U1.T16 (GND[27]), U2.6 (VSSQ), U2.12 (VSSQ), U2.28 (VSS), U2.41 (VSS), U2.46 (VSSQ), U2.52 (VSSQ), U2.54 (VSS), U5.2 (GND), U6.2 (GND), U7.2 (GND), VGA1.0 (PAD), VGA1.5, VGA1.6, VGA1.7, VGA1.8, VGA1.10, Y1.2 (CASE_GND)
unnamed: C17.1, FB2.2, J2.1 (VBUS)
unnamed: C37.2, R48.2, R49.1, U5.6 (FB)
unnamed: C38.2, R50.2, R51.1, U6.6 (FB)
unnamed: D1.2 (A), R42.2
unnamed: J1.A5 (CC1), R5.1
unnamed: J1.B5 (CC2), R10.1
unnamed: L1.1, U5.3 (SW)
unnamed: L2.1, U6.3 (SW)

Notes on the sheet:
M I N Z E
PWR3V3 COMES UP FIRST FOR MASTER SPI MODE, ECP5 DATASHEET SECTION 3.5
0.6 * (1 + (210/47)) = 3.28
MMOD has a 10K pull-up on CSPI_SS
0.6 * (1 + (100/120)) = 1.099
9-bit VGA DAC (RGB333)

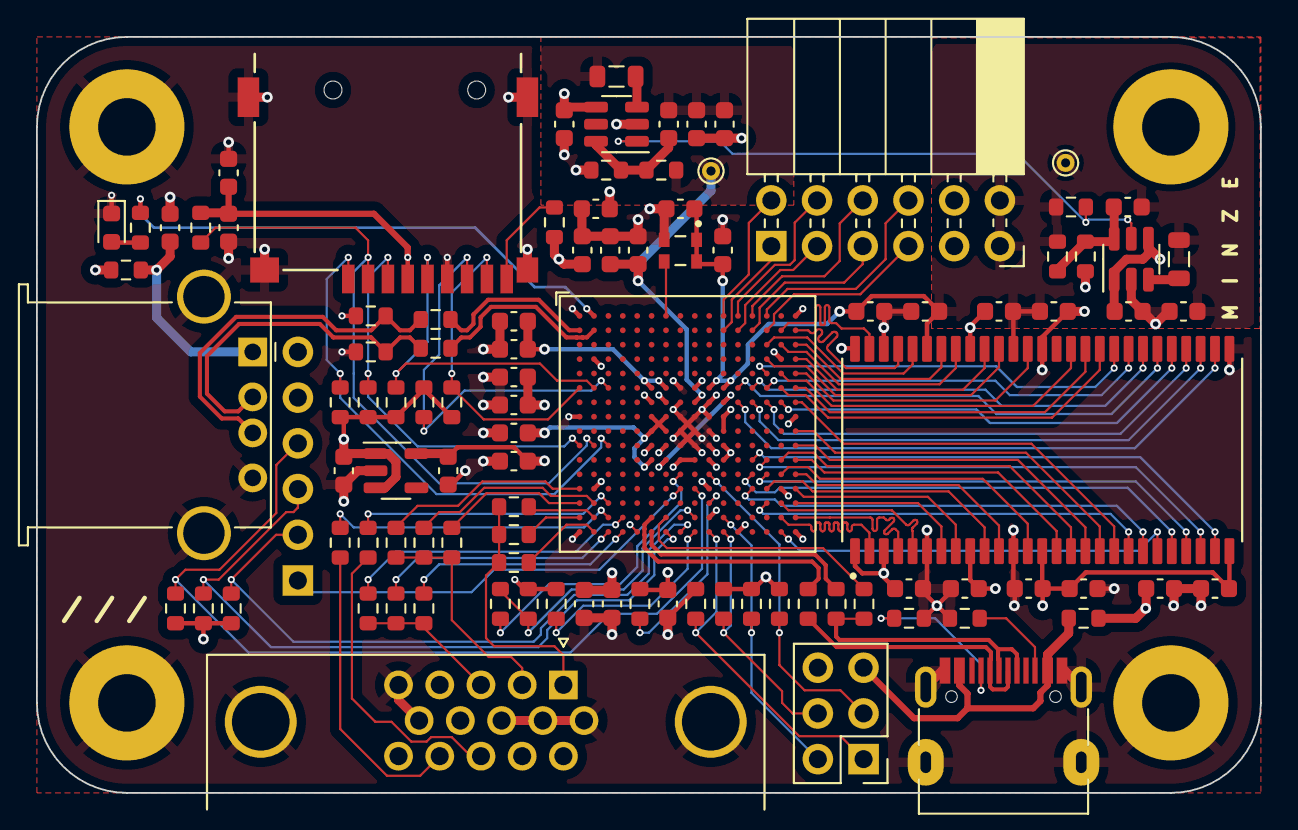
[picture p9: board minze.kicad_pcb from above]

Board: 4 copper layers, 68.0 x 42.0 mm, 105 parts (1 on the bottom side), 108 nets.

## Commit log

2023-12-11 rename kicad files
    [minze.kicad_pcb, minze.kicad_sch]
2023-12-28 add case
    [minze.scad]
2023-12-31 minor structural improvements
    [minze.scad]
2024-05-29 increase bottom height
    [minze.scad]

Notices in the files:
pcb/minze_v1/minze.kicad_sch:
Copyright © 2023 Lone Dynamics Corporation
